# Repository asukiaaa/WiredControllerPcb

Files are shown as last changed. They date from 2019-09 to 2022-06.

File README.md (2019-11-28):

# WiredControllerPcb

A wired controller that communicate in I2C with using [a library](https://github.com/asukiaaa/WiredController_asukiaaa).

# Where to buy

You can buy it from SwitchSceince.

[WiredController - SwitchSceince](https://www.switch-science.com/catalog/5950/)

# License

MIT

# References

- [WiredController - SwitchSceince](https://www.switch-science.com/catalog/5950/)
- [WiredController_asukiaaa](https://github.com/asukiaaa/WiredController_asukiaaa)

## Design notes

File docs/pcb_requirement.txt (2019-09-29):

Layer--2layers
PCB Thickness--1.6mm
Dimensions--90mm * 50mm
Castellated Hole--No
PCB Color--White
Surface Finish--HASL Lead Free
Copper Weight--1oz
Different Design:--1

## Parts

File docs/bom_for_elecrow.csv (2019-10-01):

Name | Designator | Qty | Url | Memo | MPN
0603 0.1uf | C10,C9,C8,C7,C4 | 5 |  | I don’t mind vendor | CC0603KRX7R9BB104
0603 1k | R1,R2,R3,R4,R5,R6 | 6 |  | I don’t mind vendor | RC0603JR-071KL
0603 10k | R7,R8 | 2 |  | I don’t mind vendor
0603 LED green | D1,D2,D3,D4 | 4 |  | I don’t mind vendor | 17-215SYGC/S530-E2/TR8
0603 1uf | C1 | 1 |  | I don’t mind vendor | CC0603KRX7R8BB105
0603 10nf | C2 | 1 |  | I don’t mind vendor | CC0603KRX7R9BB103
0603 2.2uf | C3 | 1 |  | I don’t mind vendor | CC0603KRX7R6BB225
PS4 Joystick 2 stick set | J1 | 1 stick of 1 set | https://ja.aliexpress.com/item/32796315112.html | I don’t mind vendor
Grove Horizontal Connector | J3 | 1 | https://ja.aliexpress.com/item/32653841632.html | I don’t mind vendor
3V3 Regulator LP2985-33DBVR | U1 | 1 | https://www.digikey.jp/product-detail/en/texas-instruments/LP2985-33DBVR/296-18476-1-ND/809911 | I don’t mind vendor | LP2985-33DBVR
ATMEGA328P-MU | U2 | 1 | https://www.digikey.jp/product-detail/en/microchip-technology/ATMEGA328P-MUR/ATMEGA328P-MURCT-ND/3440953 | I don’t mind vendor
Push switch 12mm with black cap | SW1,SW2,SW3,SW4 | 4 | https://ja.aliexpress.com/item/32806223591.html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 | I don’t mind vendor

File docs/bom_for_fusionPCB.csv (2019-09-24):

Designator | MPN | Qty | Link
C10,C9,C8,C7,C4 | CC0603KRX7R9BB104 | 5
R6,R1,R2,R3,R4,R5 | RC0603JR-071KL | 6
D4,D1,D2,D3 | 17-215SYGC/S530-E2/TR8 | 4
C1 | CC0603KRX7R8BB105 | 1
C2 | CC0603KRX7R9BB103 | 1
C3 | CC0603KRX7R6BB225 | 1
J3 | 1125R-4P | 1
U1 | LP2985-33DBVR | 1
U2 | ATMEGA328P-MU | 1

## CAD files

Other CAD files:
plate/plate.FCStd
plate/plate.dxf

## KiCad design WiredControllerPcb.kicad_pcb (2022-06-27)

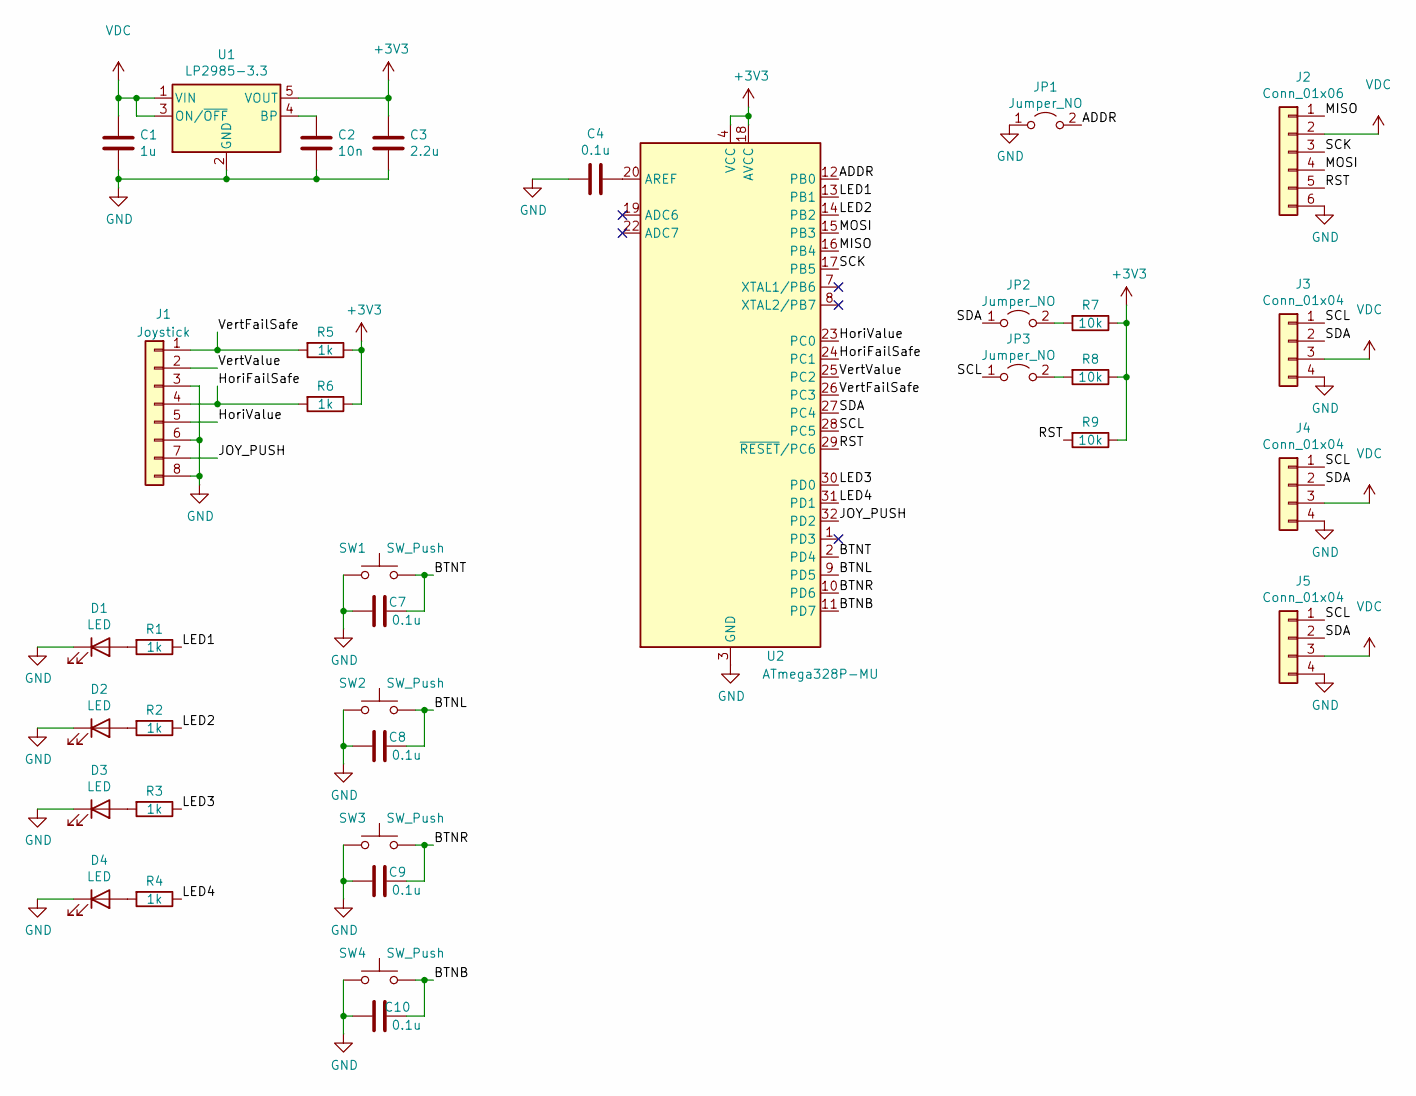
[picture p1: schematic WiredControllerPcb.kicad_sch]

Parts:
C1: 1u; C_0603_1608Metric
C2: 10n; C_0603_1608Metric
C3: 2.2u; C_0603_1608Metric
C4, C7, C8, C9, C10: 0.1u; C_0603_1608Metric
D1, D2, D3, D4: LED; LED_0603_1608Metric
J1: Joystick; PS4tJoystick
J2: Conn_01x06; 2x03_P2.54mm_Pads
J3: Conn_01x04; NS-Tech_Grove_1x04_P2mm_Horizontal
J4: Conn_01x04; TerminalBlock_bornier-4_P5.08mm
J5: Conn_01x04; PinHeader_1x04_P2.54mm_Vertical
JP1, JP2, JP3: Jumper_NO; SolderJumper-2_P1.3mm_Open_RoundedPad1.0x1.5mm
R1, R2, R3, R4, R5, R6: 1k; R_0603_1608Metric
R7, R8, R9: 10k; R_0603_1608Metric
SW1, SW2, SW3, SW4: SW_Push; SW_Center_PUSH-12mm
U1: LP2985-3.3; SOT-23-5
U2: ATmega328P-MU; QFN-32-1EP_5x5mm_P0.5mm_EP3.1x3.1mm

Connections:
+3V3: C3.1, R5.1, R6.1, R7.1, R8.1, R9.1, U1.5 (VOUT), U2.4 (VCC), U2.6 (VCC), U2.18 (AVCC)
/ADDR: JP1.2 (B), U2.12 (PB0)
/BTNB: C10.1, SW4.2, U2.11 (PD7)
/BTNL: C8.1, SW2.2, U2.9 (PD5)
/BTNR: C9.1, SW3.2, U2.10 (PD6)
/BTNT: C7.1, SW1.2, U2.2 (PD4)
/HoriFailSafe: J1.4, R6.2, U2.24 (PC1)
/HoriValue: J1.5, U2.23 (PC0)
/JOY_PUSH: J1.7, U2.32 (PD2)
/LED1: R1.1, U2.13 (PB1)
/LED2: R2.1, U2.14 (PB2)
/LED3: R3.1, U2.30 (PD0)
/LED4: R4.1, U2.31 (PD1)
/MISO: J2.1, U2.16 (PB4)
/MOSI: J2.4, U2.15 (PB3)
/RST: J2.5, R9.2, U2.29 (~RESET/PC6)
/SCK: J2.3, U2.17 (PB5)
/SCL: J3.1, J4.1, J5.1, JP3.1 (A), U2.28 (PC5)
/SDA: J3.2, J4.2, J5.2, JP2.1 (A), U2.27 (PC4)
/VertFailSafe: J1.1, R5.2, U2.26 (PC3)
/VertValue: J1.2, U2.25 (PC2)
GND: C1.2, C2.2, C3.2, C4.1, C7.2, C8.2, C9.2, C10.2, D1.1 (K), D2.1 (K), D3.1 (K), D4.1 (K), J1.3, J1.6, J1.8, J2.6, J3.4, J4.4, J5.4, JP1.1 (A), SW1.1, SW2.1, SW3.1, SW4.1, U1.2 (GND), U2.3 (GND), U2.5 (GND), U2.21 (GND), U2.33 (GND)
unnamed: C2.1, U1.4 (BP)
unnamed: C4.2, U2.20 (AREF)
unnamed: D1.2 (A), R1.2
unnamed: D2.2 (A), R2.2
unnamed: D3.2 (A), R3.2
unnamed: D4.2 (A), R4.2
unnamed: JP2.2 (B), R7.2
unnamed: JP3.2 (B), R8.2
VDC: C1.1, J2.2, J3.3, J4.3, J5.3, U1.1 (VIN), U1.3 (ON/~OFF)

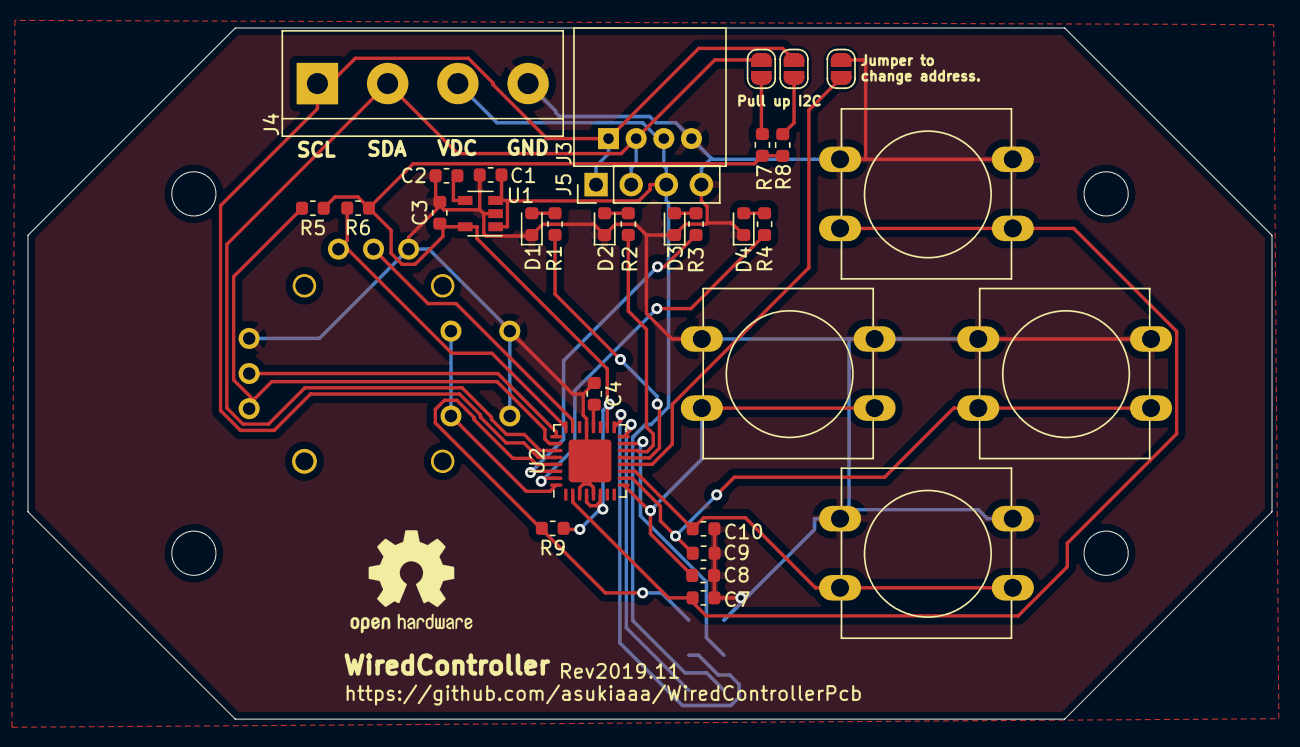
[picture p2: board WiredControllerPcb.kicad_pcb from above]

Board: 2 copper layers, 90.0 x 50.0 mm, 39 parts (1 on the bottom side), 31 nets.

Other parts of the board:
REF1, REF2, REF3, REF4: MountingHole_3.2mm_M3

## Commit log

2019-07-29 Update pcb to order rev2019.08
    [WiredControllerPcb-B_Cu.gbl, WiredControllerPcb-B_Mask.gbs, WiredControllerPcb-B_Paste.gbp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]
2019-08-25 Add plate
    [plate.FCStd, plate.dxf]
2019-09-01 Correct silk position of MOSI and GND
    [WiredControllerPcb.kicad_pcb]
2019-09-01 Correct pin assign for LED4
    [WiredControllerPcb.sch]
2019-09-01 Update symbol key for R4 ~ R6
    [WiredControllerPcb.sch]
2019-09-02 Apply 2x03 pads for 6pins
    [WiredControllerPcb.sch]
2019-09-05 Update crystal for bom and schema
    [WiredControllerPcb.sch, bom_for_fusionPCB.csv]
2019-09-05 Update connector on bom
    [bom_for_fusionPCB.csv]
2019-09-10 Remove uart connector and use 0 and 1 to LEDs
    [WiredControllerPcb.sch]
2019-09-15 Update hole position of PS4Joystick
2019-09-15 Remove crystal, change leds and replace miso and mosi
    [WiredControllerPcb.sch]
2019-09-15 Repalce VCC to VCD
    [WiredControllerPcb.sch]
2019-09-16 Add pull up resistors and jumpers for sda and scl
    [WiredControllerPcb.sch]
2019-09-17 Add terminal block
    [WiredControllerPcb.sch]
2019-09-20 Add pin header
    [WiredControllerPcb.sch]
2019-09-21 Update pcb design for revision 2019.09
    [WiredControllerPcb.kicad_pcb]
2019-09-21 Add gerber_to_order directory to .gitignore
2019-09-24 Remove un used component from bom for fusionPCB
    [bom_for_fusionPCB.csv]
2019-09-24 Add bom for elecrow
    [bom_for_elecrow.csv]
2019-09-29 Specify color of led on bom for elecrow
    [bom_for_elecrow.csv]
2019-09-29 Add pcb requirement
2019-09-30 Change resister to pullup to 10k from 1k
    [WiredControllerPcb.kicad_pcb, WiredControllerPcb.sch, bom_for_elecrow.csv]
2019-10-01 Remove wrong MPN for 10k resister on bom for elecrow
    [bom_for_elecrow.csv]
2019-11-12 Correct connection ADDR and GND
    [WiredControllerPcb.kicad_pcb]
2019-11-17 Correct position of right button and bottom button
    [WiredControllerPcb.kicad_pcb]
2020-02-09 Add pull up resistor to reset pin
    [WiredControllerPcb.kicad_pcb, WiredControllerPcb.sch]
2022-06-27 Update for KiCad6
    [WiredControllerPcb.kicad_pcb, WiredControllerPcb.kicad_sch, WiredControllerPcb.sch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]
